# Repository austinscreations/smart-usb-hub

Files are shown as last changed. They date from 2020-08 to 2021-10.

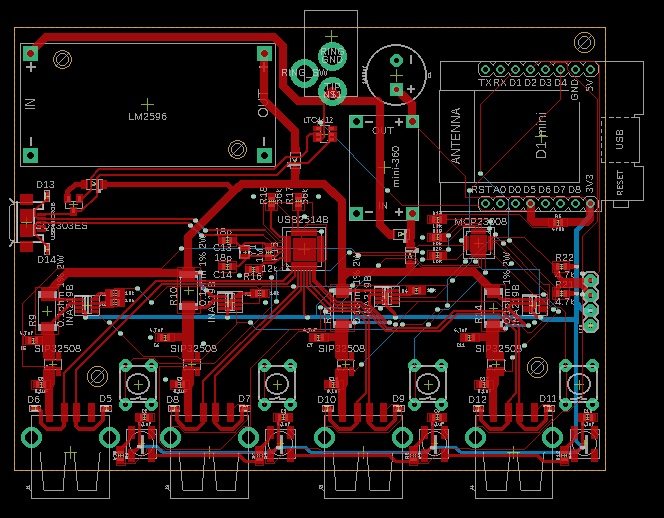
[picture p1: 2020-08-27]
version 2/design 1/pcb layout.jpg

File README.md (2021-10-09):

# smart-usb-hub
a custom usb hub for tinkers that can interface with smart home systems and provide data on power usage of a device.

2020-10-08 
added CAD files for usb2.0 for those who may want to 3d print their own case

2020-08-27
version 2 is created, has 4 usb ports, mosfet is rated for 3 amps, external power supply notifies the MCU which can allow increased current alotment in programming. eg: max 500ma under usb input vs max 5A (shared by all ports) under power supply usage (current limited by dc-dc converter)

INA219 shunt is 0.1ohm 2W 1% toleance which allows for sense current up to 3.2Amps.

version 2 now includes 4 ports using usb2514 for hub control.

board allows for buttons to be placed and allows for software control of outputs -- newpixels give the ability to iniicate status of ports. 4 pin header spot has been added for the use of an I2C LCD.

current design allows for various arengments of a custom 3D printed case that allows the hub to me mounted in various ways

current board size is 100*75mm

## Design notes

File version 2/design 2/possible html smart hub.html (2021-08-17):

## %title% Home

Home

Management

Dark Mode

ONLINE

IP Address: %ipplaceholder%

MAC Address: %macplaceholder%

Volts:

Amps:

Power:

Data:

CMND:

5.08

0.00

Disabled

Disabled

SINGLE

Toggle

Volts:

Amps:

Power:

Data:

CMND:

5.08

0.00

Disabled

Disabled

SINGLE

Toggle

Volts:

Amps:

Power:

Data:

CMND:

5.08

0.00

Disabled

Disabled

SINGLE

Toggle

Volts:

Amps:

Power:

Data:

CMND:

5.08

0.00

Disabled

Disabled

SINGLE

Toggle

%IDplaceholder% - %processorplaceholder% - %typeplaceholder%

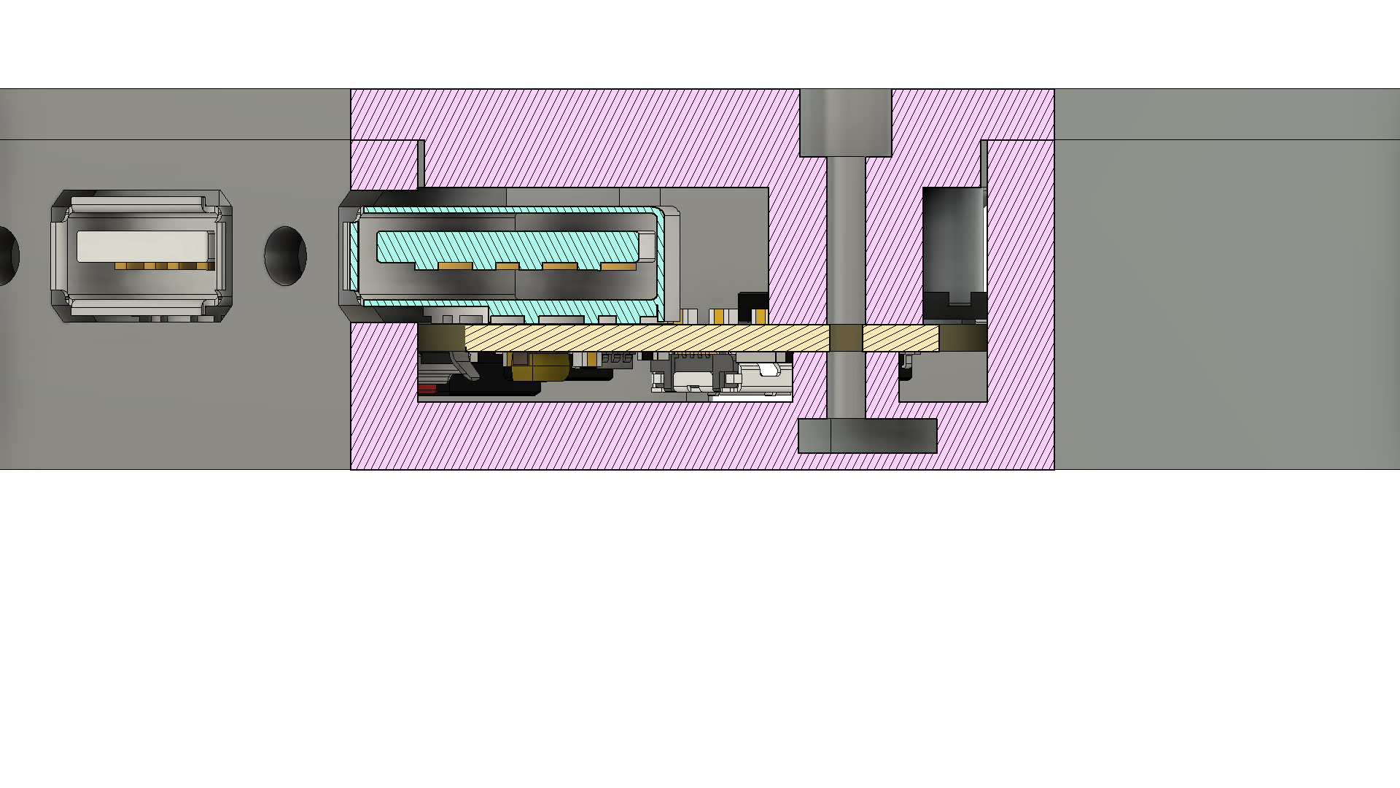
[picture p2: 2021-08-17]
version 2/design 2/cross section/corner cross section case 1.png

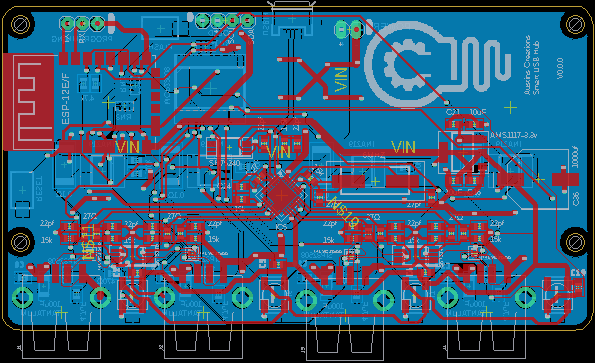
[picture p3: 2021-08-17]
version 2/design 2/v1/PCB.png

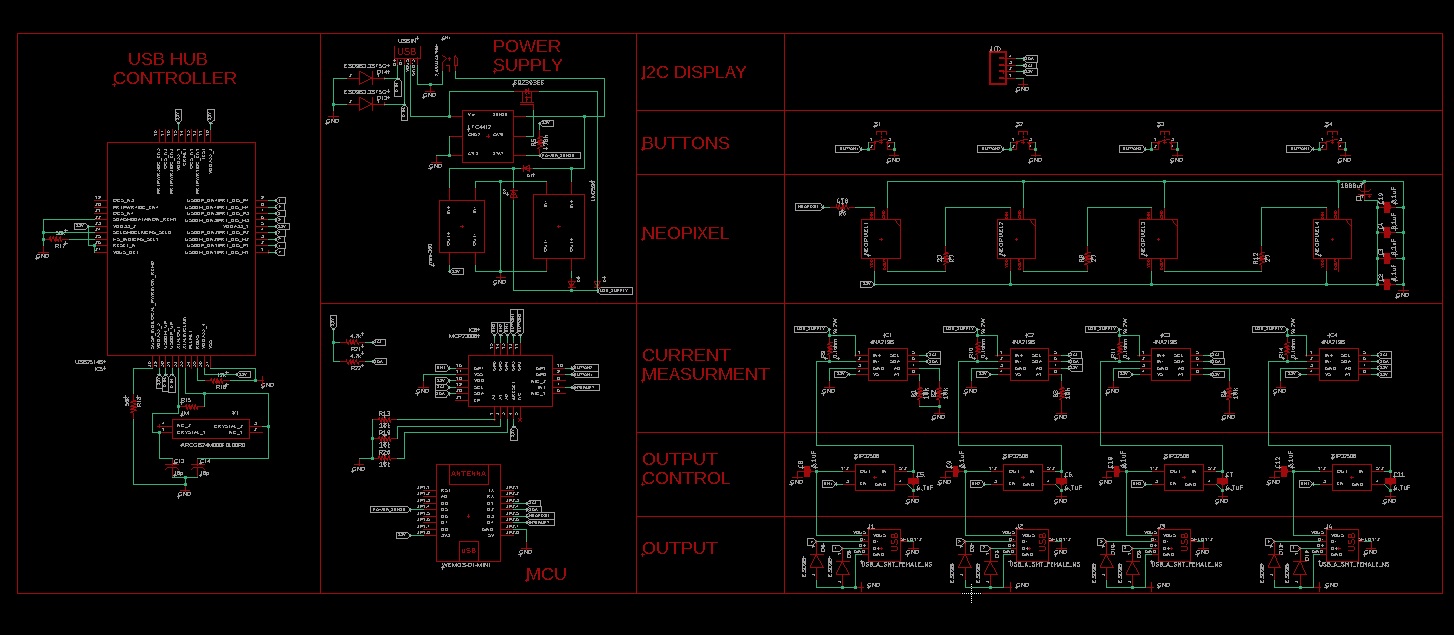
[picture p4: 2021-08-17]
version 2/design 1/schematic layout 2.jpg

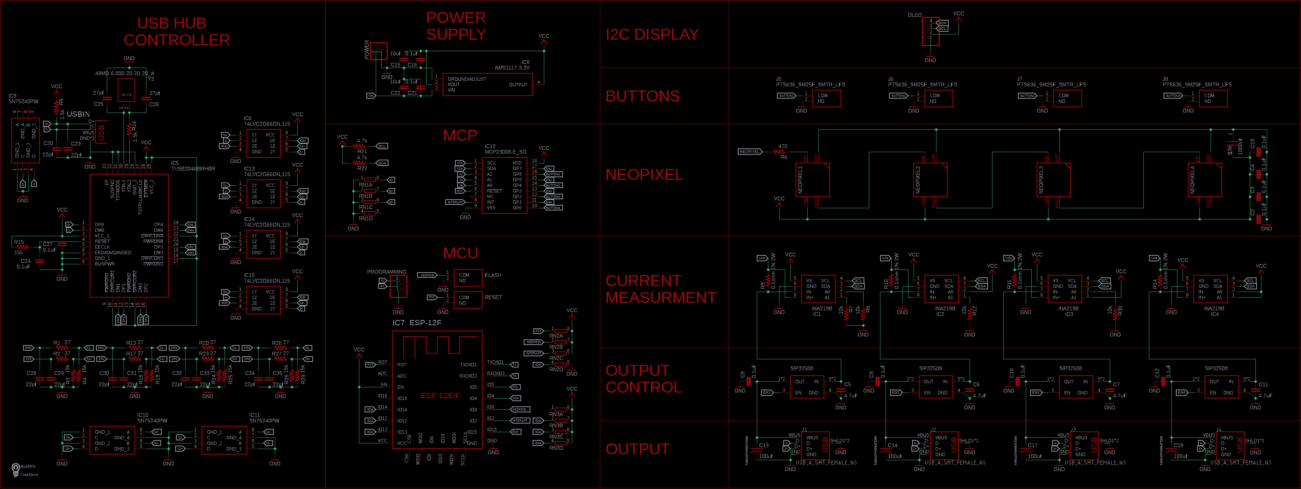
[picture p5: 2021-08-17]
version 2/design 2/v1/schematic.png

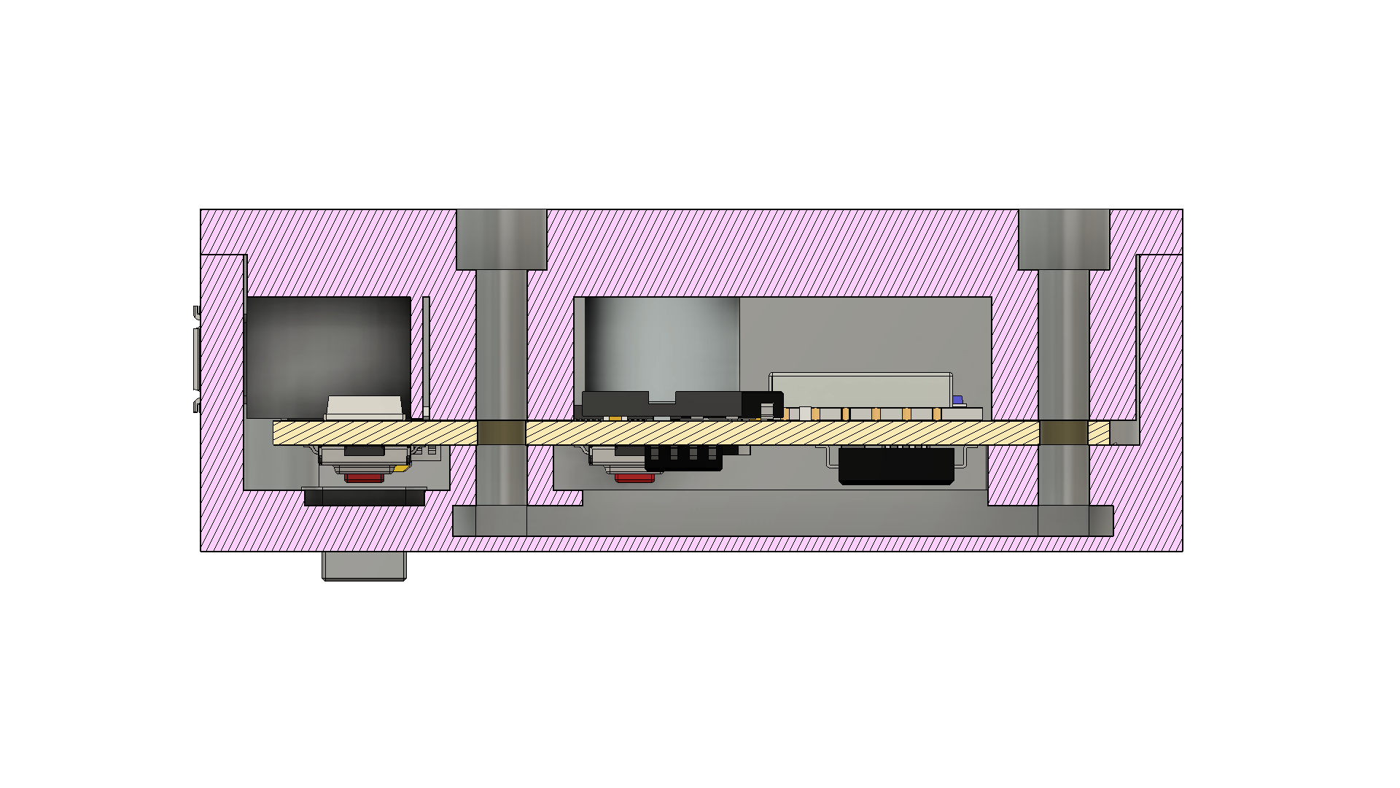
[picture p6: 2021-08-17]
version 2/design 2/cross section/side a cross section case 1.png

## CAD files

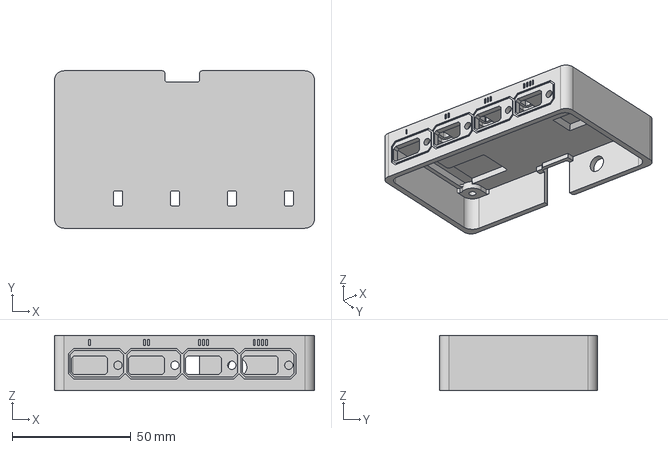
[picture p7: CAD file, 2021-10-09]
version 2/design 2/CAD/step/base.step
109.6 x 66.4 x 23.3 mm

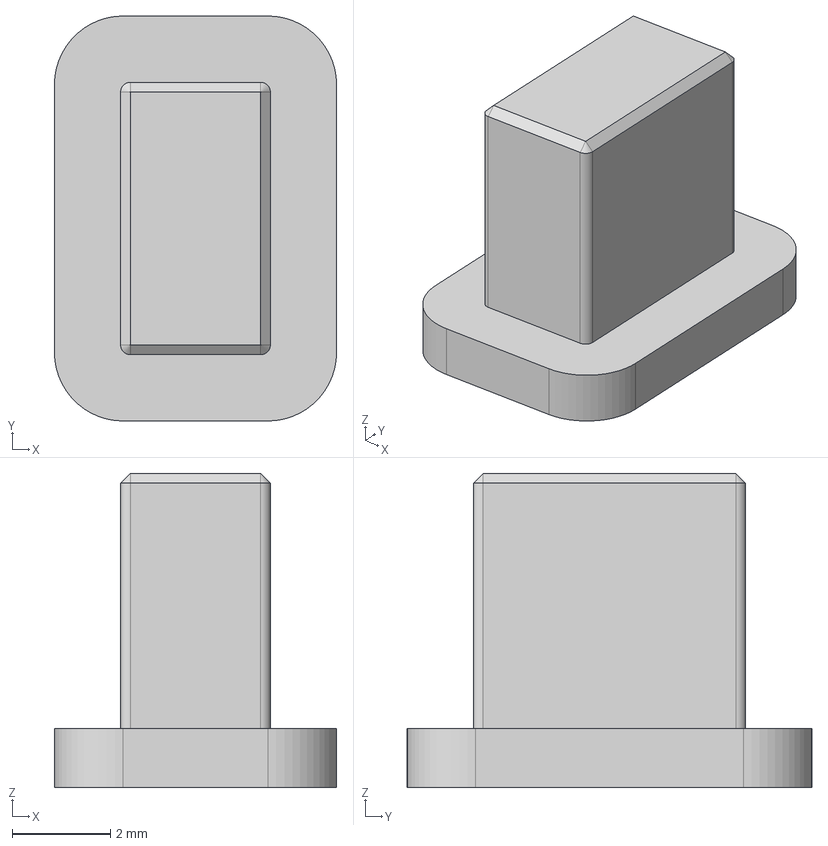
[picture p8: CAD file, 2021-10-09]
version 2/design 2/CAD/step/button.step
5.75 x 8.25 x 6.40 mm

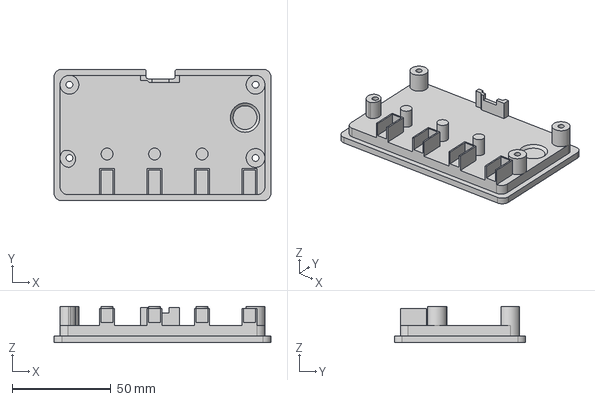
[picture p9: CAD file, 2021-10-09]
version 2/design 2/CAD/step/lid.step
109.6 x 66.4 x 18.2 mm

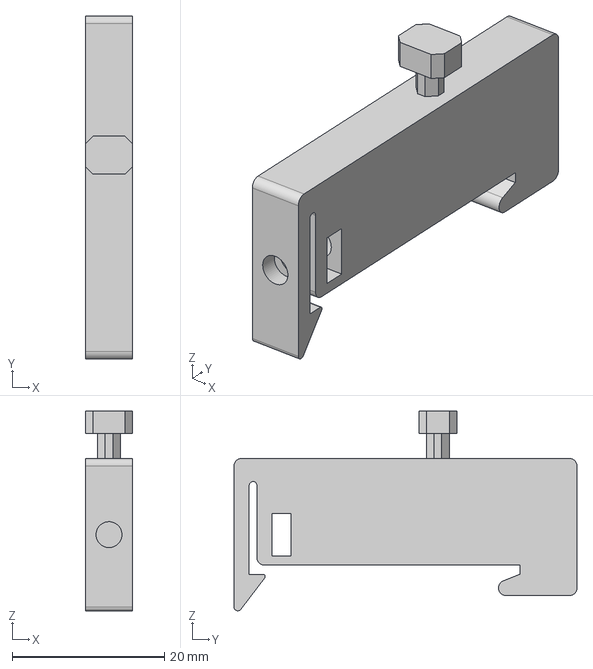
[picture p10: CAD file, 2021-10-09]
version 2/design 2/CAD/step/din rail mount.step
6.20 x 45.0 x 26.2 mm

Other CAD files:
version 2/design 2/CAD/stl/base.stl
version 2/design 2/CAD/stl/button.stl
version 2/design 2/CAD/stl/din rail mount.stl
version 2/design 2/CAD/stl/lid.stl

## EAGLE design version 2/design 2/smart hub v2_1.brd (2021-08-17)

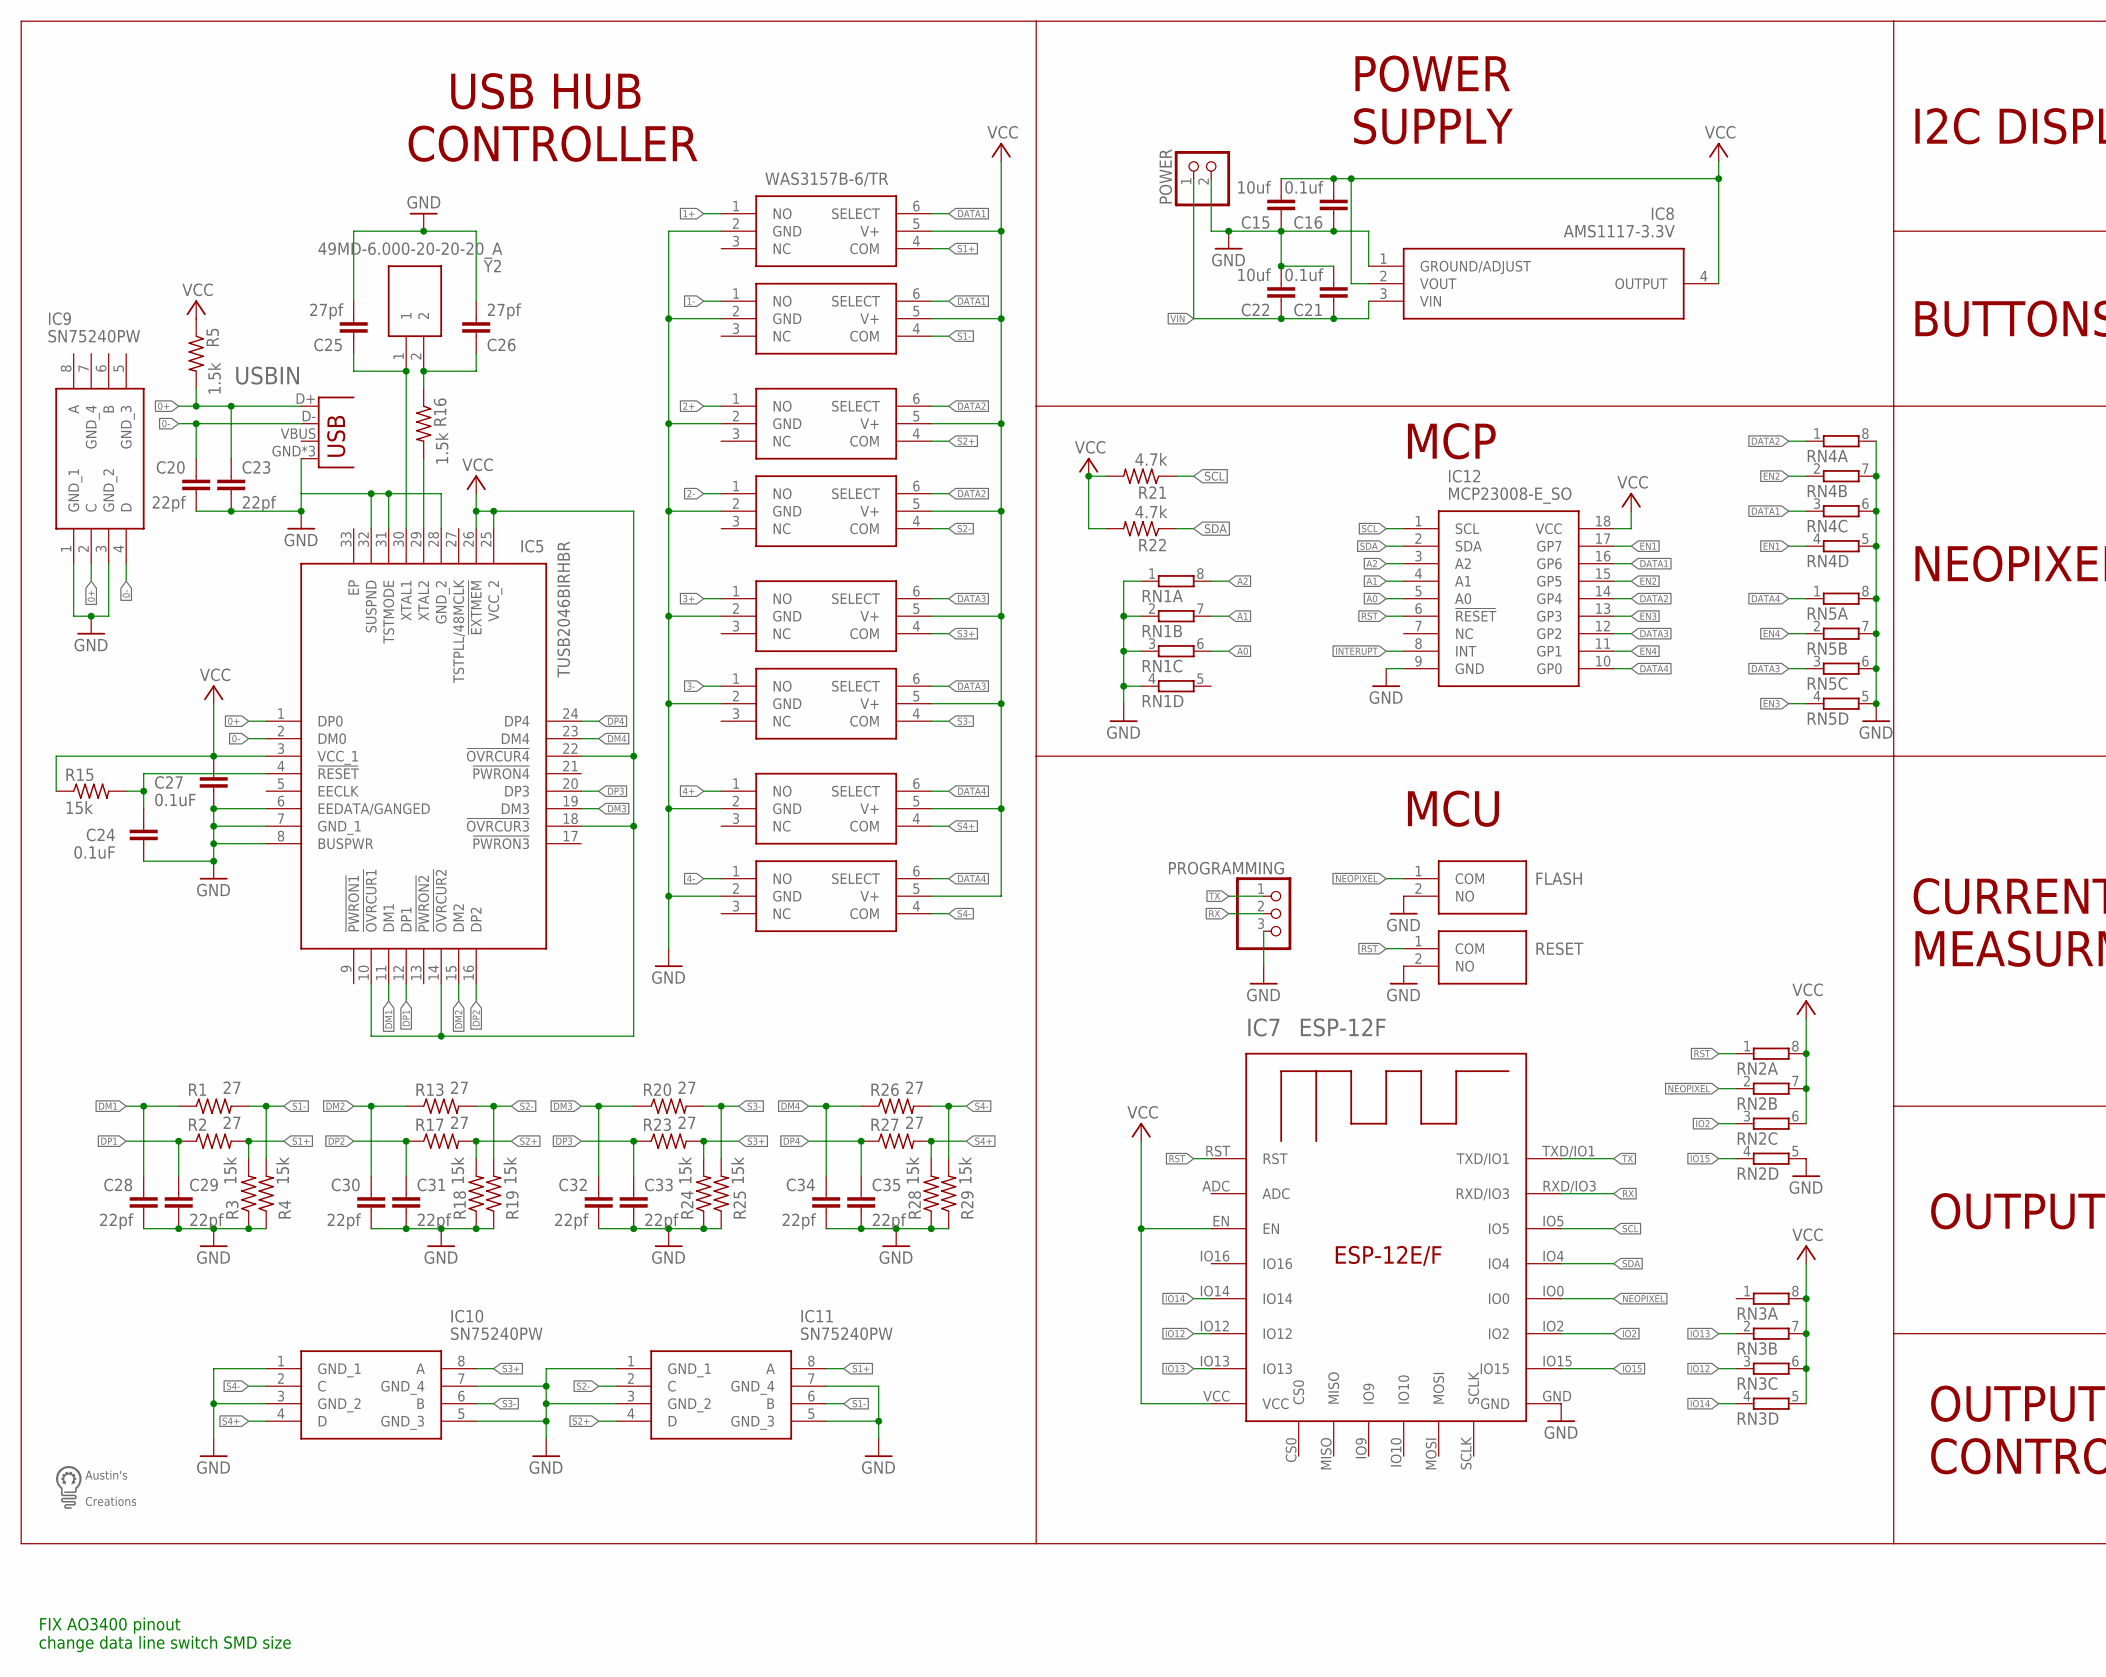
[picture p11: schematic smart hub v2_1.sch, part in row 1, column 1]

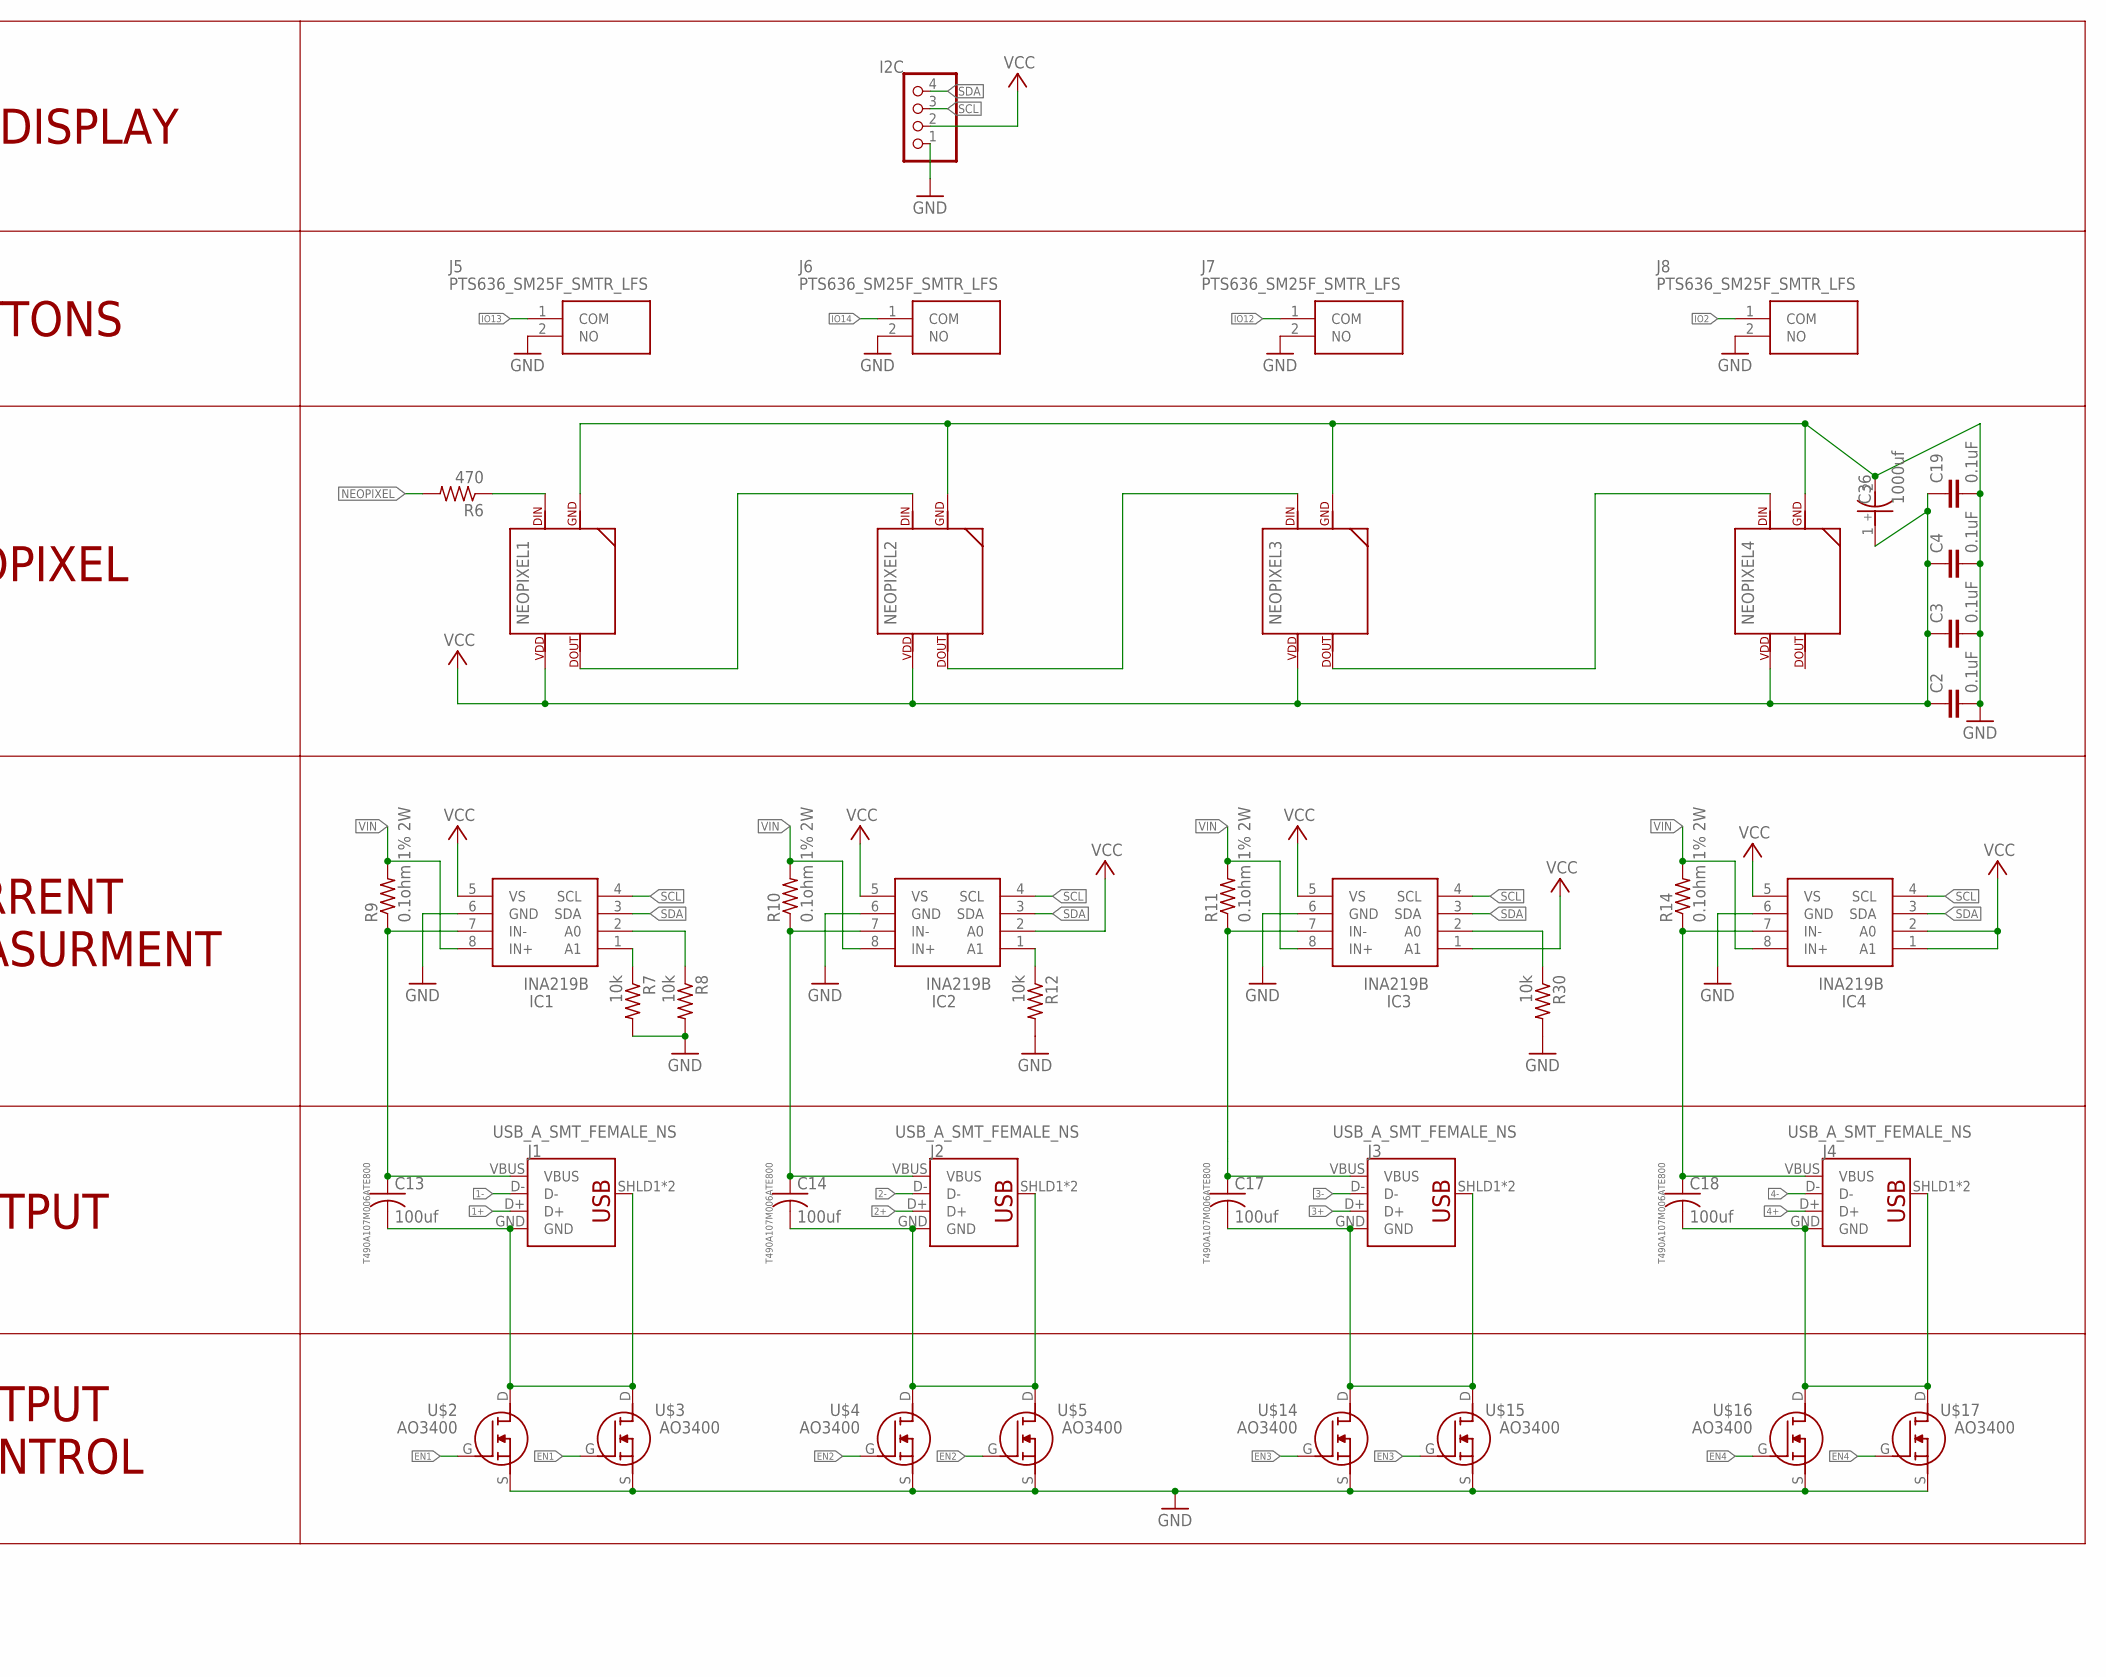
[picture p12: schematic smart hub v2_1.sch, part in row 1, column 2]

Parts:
C2, C3, C4, C19, C24, C27: 0.1uF; C0603
C13, C14, C17, C18: 100uf; C1206
C15, C22: 10uf; C0603
C16, C21: 0.1uf; C0603
C20, C23, C28, C29, C30, C31, C32, C33, C34, C35: 22pf; C0603
C25, C26: 27pf; C0603
C36: 1000uf; CAPAE1030X1050N
FLASH: PTS636_SM25F_SMTR_LFS; PTS636SM25FSMTRLFS
I2C: PINHD-1X4; 1X04
IC1, IC2, IC3, IC4: INA219B; SOIC127P600X175-8N
IC5: TUSB2046BIRHBR; QFN50P500X500X100-33N
IC7: ESP-12F; ESP-12E
IC8: AMS1117-3.3V; SOT229P700X180-4N
IC9, IC10, IC11: SN75240PW; SOP65P640X120-8N
IC12: MCP23008-E_SO; SOIC127P1030X265-18N
J1, J2, J3, J4: USB_A_SMT_FEMALE_NS; USB-A-S-NOSILK-FEMALE
J5, J6, J7, J8: PTS636_SM25F_SMTR_LFS; PTS636SM25FSMTRLFS
NEOPIXEL1, NEOPIXEL2, NEOPIXEL3, NEOPIXEL4: SK6812NEOPIXEL5050; SK6812
POWER: PINHD-1X2; 1X02
PROGRAMMING: PINHD-1X3; 1X03
R1, R2, R13, R17, R20, R23, R26, R27: 27; R0603
R3, R4, R15, R18, R19, R24, R25, R28, R29: 15k; R0603
R5, R16: 1.5k; R0603
R6: 470; R0603
R7, R8, R12, R30: 10k; R0603
R9, R10, R11, R14: 0.1ohm 1% 2W; R2512W
R21, R22: 4.7k; R0603
RESET: PTS636_SM25F_SMTR_LFS; PTS636SM25FSMTRLFS
RN1, RN2, RN3, RN4, RN5: 4R-N0603-ARC; 0603-ARC
U$1: LOGOMASSIVE
U$2, U$3, U$4, U$5, U$14, U$15, U$16, U$17: AO3400
U$6, U$7, U$8, U$9, U$10, U$11, U$12, U$13: WAS3157B-6/TR
USBIN: USB-MICROB
Y2: 49MD-6.000-20-20-20_A; 49MD6000202020A

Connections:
0+: C23.1, IC5.1 (DP0), IC9.2 (C), R5.2, USBIN.D+
0-: C20.1, IC5.2 (DM0), IC9.4 (D), USBIN.D-
1+: J1.D+, U$6.1 (NO)
1-: J1.D-, U$7.1 (NO)
2+: J2.D+, U$8.1 (NO)
2-: J2.D-, U$9.1 (NO)
3+: J3.D+, U$10.1 (NO)
3-: J3.D-, U$11.1 (NO)
4+: J4.D+, U$12.1 (NO)
4-: J4.D-, U$13.1 (NO)
A0: IC12.5 (A0), RN1.6 (2)
A1: IC12.4 (A1), RN1.7 (2)
A2: IC12.3 (A2), RN1.8 (2)
DATA1: IC12.16 (GP6), RN4.3 (1), U$6.6 (SELECT), U$7.6 (SELECT)
DATA2: IC12.14 (GP4), RN4.1, U$8.6 (SELECT), U$9.6 (SELECT)
DATA3: IC12.12 (GP2), RN5.3 (1), U$10.6 (SELECT), U$11.6 (SELECT)
DATA4: IC12.10 (GP0), RN5.1, U$12.6 (SELECT), U$13.6 (SELECT)
DM1: C28.1, IC5.11 (DM1), R1.1
DM2: C30.1, IC5.15 (DM2), R13.1
DM3: C32.1, IC5.19 (DM3), R20.1
DM4: C34.1, IC5.23 (DM4), R26.1
DP1: C29.1, IC5.12 (DP1), R2.1
DP2: C31.1, IC5.16 (DP2), R17.1
DP3: C33.1, IC5.20 (DP3), R23.1
DP4: C35.1, IC5.24 (DP4), R27.1
EN1: IC12.17 (GP7), RN4.4 (1), U$2.G, U$3.G
EN2: IC12.15 (GP5), RN4.2 (1), U$4.G, U$5.G
EN3: IC12.13 (GP3), RN5.4 (1), U$14.G, U$15.G
EN4: IC12.11 (GP1), RN5.2 (1), U$16.G, U$17.G
GND: C2.2, C3.2, C4.2, C15.1, C16.1, C19.2, C20.2, C21.2, C22.2, C23.2, C24.2, C25.2, C26.2, C27.2, C28.2, C29.2, C30.2, C31.2, C32.2, C33.2, C34.2, C35.2, C36.2 (-), FLASH.2 (NO), I2C.1, IC1.6 (GND), IC2.6 (GND), IC3.6 (GND), IC4.6 (GND), IC5.6 (EEDATA/GANGED), IC5.7 (GND_1), IC5.8 (BUSPWR), IC5.28 (GND_2), IC5.31 (TSTMODE), IC5.32 (SUSPND), IC7.GND, IC8.1 (GROUND/ADJUST), IC9.1 (GND_1), IC9.3 (GND_2), IC10.1 (GND_1), IC10.3 (GND_2), IC10.5 (GND_3), IC10.7 (GND_4), IC11.1 (GND_1), IC11.3 (GND_2), IC11.5 (GND_3), IC11.7 (GND_4), IC12.9 (GND), J5.2 (NO), J6.2 (NO), J7.2 (NO), J8.2 (NO), NEOPIXEL1.3 (GND), NEOPIXEL2.3 (GND), NEOPIXEL3.3 (GND), NEOPIXEL4.3 (GND), POWER.2, PROGRAMMING.3, R3.1, R4.1, R7.2, R8.2, R12.2, R18.1, R19.1, R24.1, R25.1, R28.1, R29.1, R30.2, RESET.2 (NO), RN1.1, RN1.2 (1), RN1.3 (1), RN1.4 (1), RN2.5 (2), RN4.5 (2), RN4.6 (2), RN4.7 (2), RN4.8 (2), RN5.5 (2), RN5.6 (2), RN5.7 (2), RN5.8 (2), U$2.S, U$3.S, U$4.S, U$5.S, U$6.2 (GND), U$7.2 (GND), U$8.2 (GND), U$9.2 (GND), U$10.2 (GND), U$11.2 (GND), U$12.2 (GND), U$13.2 (GND), U$14.S, U$15.S, U$16.S, U$17.S, USBIN.GND, USBIN.MT1 (GND), USBIN.MT2 (GND)
INTERUPT: IC12.8 (INT)
IO2: IC7.IO2, J8.1 (COM), RN2.3 (1)
IO12: IC7.IO12, J7.1 (COM), RN3.3 (1)
IO13: IC7.IO13, J5.1 (COM), RN3.2 (1)
IO14: IC7.IO14, J6.1 (COM), RN3.4 (1)
IO15: IC7.IO15, RN2.4 (1)
unnamed: C13.2, J1.GND, J1.SHLD1 (SHIELD), J1.SHLD2 (SHIELD), U$2.D, U$3.D
unnamed: C14.2, J2.GND, J2.SHLD1 (SHIELD), J2.SHLD2 (SHIELD), U$4.D, U$5.D
unnamed: C25.1, IC5.30 (XTAL1), Y2.1
unnamed: C24.1, IC5.4 (!RESET), R15.2
unnamed: C26.1, R16.1, Y2.2
unnamed: C17.2, J3.GND, J3.SHLD1 (SHIELD), J3.SHLD2 (SHIELD), U$14.D, U$15.D
unnamed: IC5.29 (XTAL2), R16.2
unnamed: NEOPIXEL1.2 (DOUT), NEOPIXEL2.4 (DIN)
unnamed: NEOPIXEL2.2 (DOUT), NEOPIXEL3.4 (DIN)
unnamed: C18.2, J4.GND, J4.SHLD1 (SHIELD), J4.SHLD2 (SHIELD), U$16.D, U$17.D
unnamed: IC3.2 (A0), R30.1
unnamed: IC2.1 (A1), R12.1
unnamed: IC1.1 (A1), R7.1
unnamed: IC1.2 (A0), R8.1
unnamed: NEOPIXEL1.4 (DIN), R6.1
unnamed: C13.1, IC1.7 (IN-), J1.VBUS, R9.1
unnamed: NEOPIXEL3.2 (DOUT), NEOPIXEL4.4 (DIN)
unnamed: C14.1, IC2.7 (IN-), J2.VBUS, R10.1
unnamed: C17.1, IC3.7 (IN-), J3.VBUS, R11.1
unnamed: C18.1, IC4.7 (IN-), J4.VBUS, R14.1
NEOPIXEL: FLASH.1 (COM), IC7.IO0, R6.2, RN2.2 (1)
RST: IC7.RST, IC12.6 (!RESET), RESET.1 (COM), RN2.1
RX: IC7.RXD/IO3, PROGRAMMING.2
S1+: IC11.8 (A), R2.2, R3.2, U$6.4 (COM)
S1-: IC11.6 (B), R1.2, R4.2, U$7.4 (COM)
S2+: IC11.4 (D), R17.2, R18.2, U$8.4 (COM)
S2-: IC11.2 (C), R13.2, R19.2, U$9.4 (COM)
S3+: IC10.8 (A), R23.2, R24.2, U$10.4 (COM)
S3-: IC10.6 (B), R20.2, R25.2, U$11.4 (COM)
S4+: IC10.4 (D), R27.2, R28.2, U$12.4 (COM)
S4-: IC10.2 (C), R26.2, R29.2, U$13.4 (COM)
SCL: I2C.3, IC1.4 (SCL), IC2.4 (SCL), IC3.4 (SCL), IC4.4 (SCL), IC7.IO5, IC12.1 (SCL), R21.1
SDA: I2C.4, IC1.3 (SDA), IC2.3 (SDA), IC3.3 (SDA), IC4.3 (SDA), IC7.IO4, IC12.2 (SDA), R22.1
TX: IC7.TXD/IO1, PROGRAMMING.1
VCC: C2.1, C3.1, C4.1, C15.2, C16.2, C19.1, C27.1, C36.1 (+), I2C.2, IC1.5 (VS), IC2.2 (A0), IC2.5 (VS), IC3.1 (A1), IC3.5 (VS), IC4.1 (A1), IC4.2 (A0), IC4.5 (VS), IC5.3 (VCC_1), IC5.10 (!OVRCUR1), IC5.14 (!OVRCUR2), IC5.18 (!OVRCUR3), IC5.22 (!OVRCUR4), IC5.25 (VCC_2), IC5.26 (!EXTMEM), IC7.EN, IC7.VCC, IC8.2 (VOUT), IC8.4 (OUTPUT), IC12.18 (VCC), NEOPIXEL1.1 (VDD), NEOPIXEL2.1 (VDD), NEOPIXEL3.1 (VDD), NEOPIXEL4.1 (VDD), R5.1, R15.1, R21.2, R22.2, RN2.6 (2), RN2.7 (2), RN2.8 (2), RN3.5 (2), RN3.6 (2), RN3.7 (2), RN3.8 (2), U$6.5 (V+), U$7.5 (V+), U$8.5 (V+), U$9.5 (V+), U$10.5 (V+), U$11.5 (V+), U$12.5 (V+), U$13.5 (V+)
VIN: C21.1, C22.1, IC1.8 (IN+), IC2.8 (IN+), IC3.8 (IN+), IC4.8 (IN+), IC8.3 (VIN), POWER.1, R9.2, R10.2, R11.2, R14.2

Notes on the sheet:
I2C DISPLAY
BUTTONS
NEOPIXEL
CURRENT MEASURMENT
OUTPUT CONTROL
OUTPUT
POWER SUPPLY
USB HUB CONTROLLER
MCU
MCP
T490A107M006ATE800
FIX AO3400 pinout change data line switch SMD size

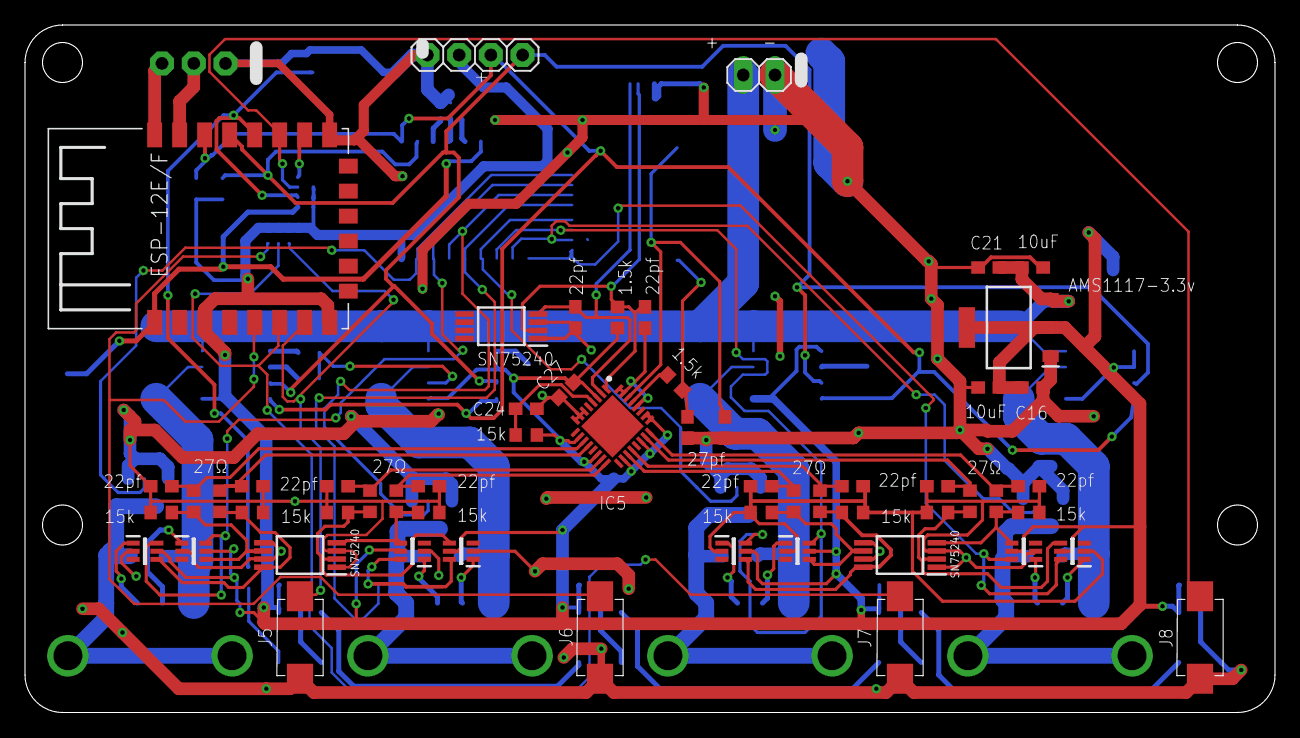
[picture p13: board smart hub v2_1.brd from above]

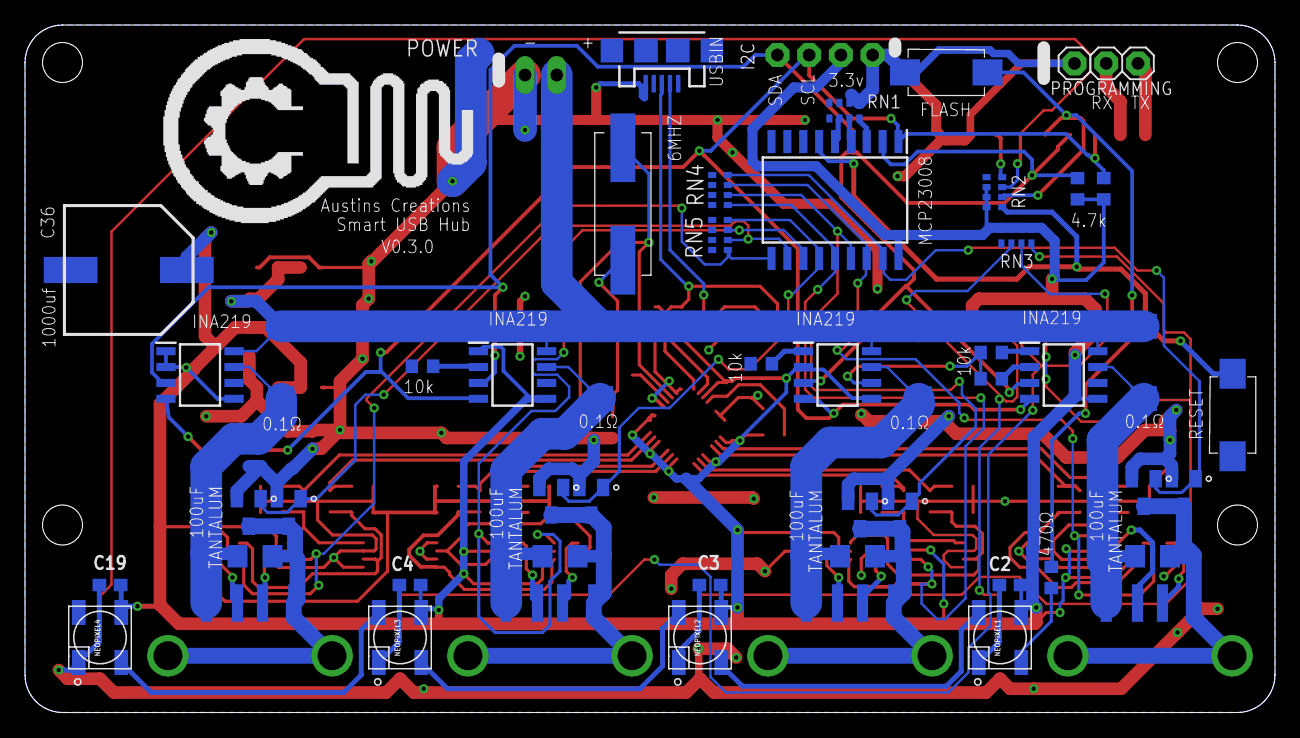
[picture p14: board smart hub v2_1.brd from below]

Board: 2 copper layers, 100.0 x 55.0 mm, 109 parts (52 on the bottom side), 71 nets.

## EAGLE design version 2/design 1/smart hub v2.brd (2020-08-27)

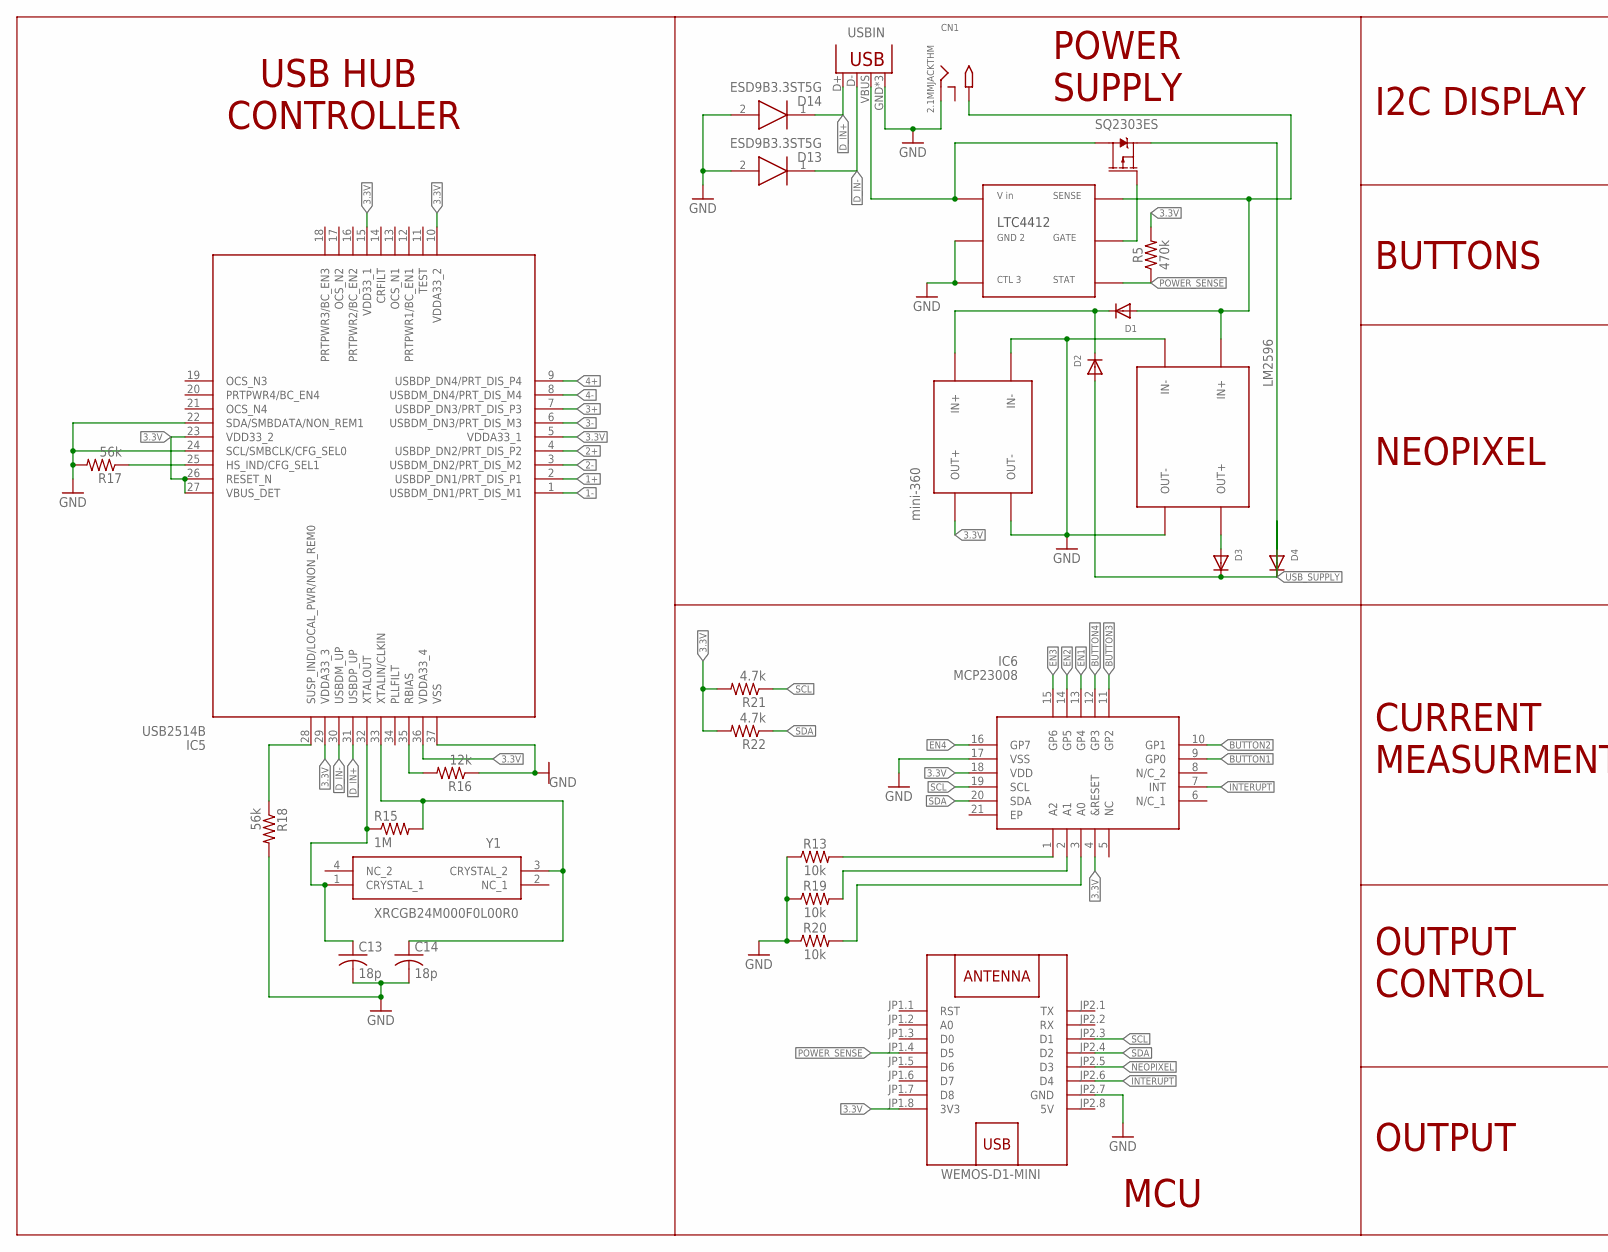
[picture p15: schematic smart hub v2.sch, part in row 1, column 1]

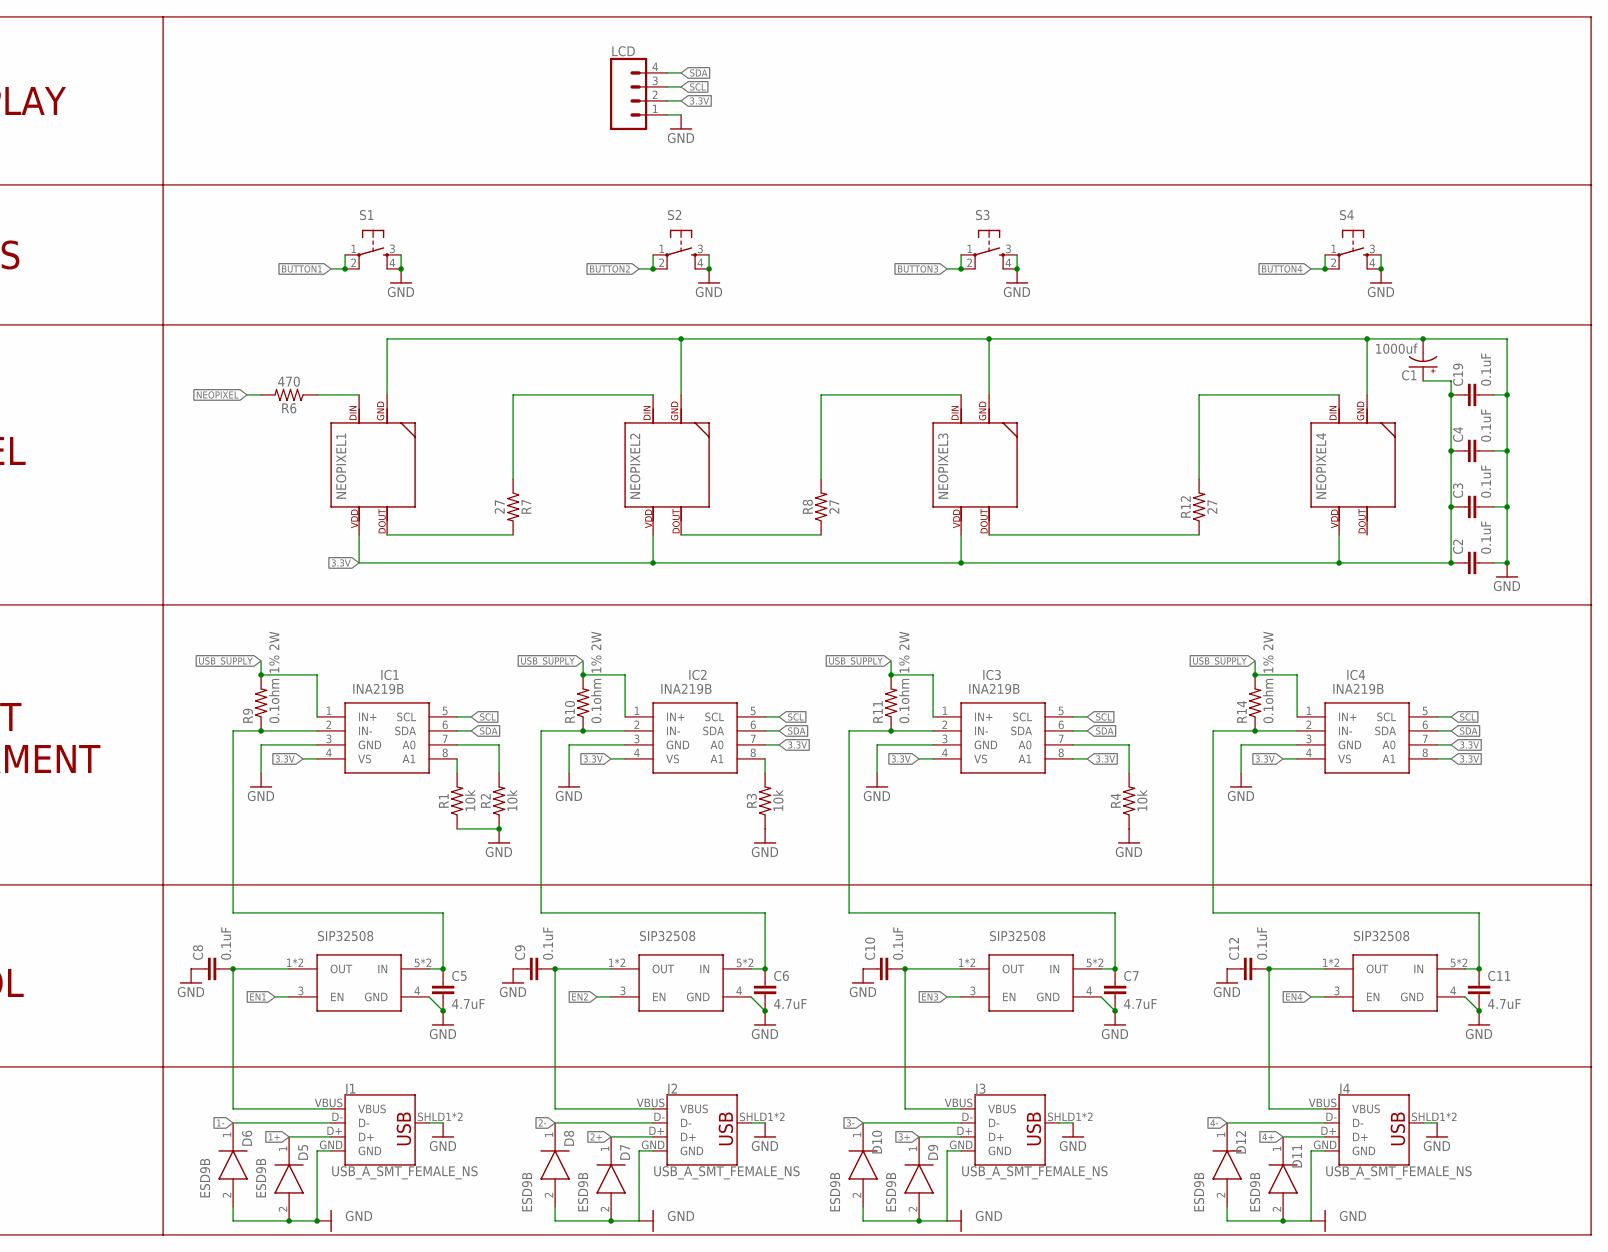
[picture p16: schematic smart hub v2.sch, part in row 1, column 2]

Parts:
C1: 1000uf; CPOL-RADIAL-5MM-10MM-KIT
C2, C3, C4, C8, C9, C10, C12, C19: 0.1uF; 0603
C5, C6, C7, C11: 4.7uF; 0603
C13, C14: 18p; C0603
CN1: 2.1MMJACKTHM; PJ-102A
D1, D2, D3, D4: DIODE_SOD-123FL; SOD-123FL
D5, D6, D7, D8, D9, D10, D11, D12: ESD9B; SODFL1006X40N
D13, D14: ESD9B3.3ST5G; SODFL1006X40N
IC1, IC2, IC3, IC4: INA219B; SOT65P280X145-8N
IC5: USB2514B; QFN50P600X600X100-37N
IC6: MCP23008; QFN50P400X400X100-21N
J1, J2, J3, J4: USB_A_SMT_FEMALE_NS; USB-A-S-NOSILK-FEMALE
LCD: CONN_04; 1X04
LTC4412: LTC4412; TSOT23-6
NEOPIXEL1, NEOPIXEL2, NEOPIXEL3, NEOPIXEL4: SK6812NEOPIXEL5050; SK6812
R1, R2, R3, R4, R13, R19, R20: 10k; 0603
R5: 470k; 0603
R6: 470; 0603
R7, R8, R12: 27; 0603
R9, R10, R11, R14: 0.1ohm 1% 2W; R2512W
R15: 1M; R0603
R16: 12k; R0603
R17, R18: 56k; R0603
R21, R22: 4.7k; R0603
S1, S2, S3, S4: TAC_SWITCHPTH; TACTILE-PTH
U$1: WEMOS-D1-MINI
U$2: SQ2303ES; SOT23
U$3, U$4, U$5, U$8: SIP32508; SOT23-6
U$6: LM2596; DC-DC-STEP-DOWN-LM2596
U$7: mini-360; DC-DC-STEP-DOWN-MP2307
USBIN: USB-MICROB
Y1: XRCGB24M000F0L00R0; XRCGB24

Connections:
1+: D5.1 (K), IC5.2 (USBDP_DN1/PRT_DIS_P1), J1.D+
1-: D6.1 (K), IC5.1 (USBDM_DN1/PRT_DIS_M1), J1.D-
2+: D7.1 (K), IC5.4 (USBDP_DN2/PRT_DIS_P2), J2.D+
2-: D8.1 (K), IC5.3 (USBDM_DN2/PRT_DIS_M2), J2.D-
3+: D9.1 (K), IC5.7 (USBDP_DN3/PRT_DIS_P3), J3.D+
3-: D10.1 (K), IC5.6 (USBDM_DN3/PRT_DIS_M3), J3.D-
3.3V: C1.+, C2.1, C3.1, C4.1, C19.1, IC1.4 (VS), IC2.4 (VS), IC2.7 (A0), IC3.4 (VS), IC3.8 (A1), IC4.4 (VS), IC4.7 (A0), IC4.8 (A1), IC5.5 (VDDA33_1), IC5.10 (VDDA33_2), IC5.15 (VDD33_1), IC5.23 (VDD33_2), IC5.26 (RESET_N), IC5.27 (VBUS_DET), IC5.29 (VDDA33_3), IC5.36 (VDDA33_4), IC6.4 (&RESET), IC6.18 (VDD), LCD.2, NEOPIXEL1.1 (VDD), NEOPIXEL2.1 (VDD), NEOPIXEL3.1 (VDD), NEOPIXEL4.1 (VDD), R5.2, R21.2, R22.2, U$1.JP1.8 (3V3), U$7.OUT+
4+: D11.1 (K), IC5.9 (USBDP_DN4/PRT_DIS_P4), J4.D+
4-: D12.1 (K), IC5.8 (USBDM_DN4/PRT_DIS_M4), J4.D-
5V: U$1.JP2.8 (5V)
BUTTON1: IC6.9 (GP0), S1.1, S1.2
BUTTON2: IC6.10 (GP1), S2.1, S2.2
BUTTON3: IC6.11 (GP2), S3.1, S3.2
BUTTON4: IC6.12 (GP3), S4.1, S4.2
D_IN+: D14.1 (K), IC5.31 (USBDP_UP), USBIN.D+
D_IN-: D13.1 (K), IC5.30 (USBDM_UP), USBIN.D-
EN1: IC6.13 (GP4), U$3.3 (EN)
EN2: IC6.14 (GP5), U$4.3 (EN)
EN3: IC6.15 (GP6), U$5.3 (EN)
EN4: IC6.16 (GP7), U$8.3 (EN)
GND: C1.-, C2.2, C3.2, C4.2, C5.2, C6.2, C7.2, C8.1, C9.1, C10.1, C11.2, C12.1, C13.2, C14.2, C19.2, CN1.RING, D5.2 (A), D6.2 (A), D13.2 (A), D14.2 (A), IC1.3 (GND), IC2.3 (GND), IC3.3 (GND), IC4.3 (GND), IC5.22 (SDA/SMBDATA/NON_REM1), IC5.24 (SCL/SMBCLK/CFG_SEL0), IC5.37 (VSS), IC6.17 (VSS), J1.GND, J1.SHLD1 (SHIELD), J1.SHLD2 (SHIELD), J2.SHLD1 (SHIELD), J2.SHLD2 (SHIELD), J3.SHLD1 (SHIELD), J3.SHLD2 (SHIELD), J4.SHLD1 (SHIELD), J4.SHLD2 (SHIELD), LCD.1, LTC4412.2, LTC4412.3, NEOPIXEL1.3 (GND), NEOPIXEL2.3 (GND), NEOPIXEL3.3 (GND), NEOPIXEL4.3 (GND), R1.1, R2.1, R3.1, R4.1, R13.1, R16.1, R17.2, R18.2, R19.1, R20.1, S1.3, S1.4, S2.3, S2.4, S3.3, S3.4, S4.3, S4.4, U$1.JP2.7 (GND), U$3.4 (GND), U$4.4 (GND), U$5.4 (GND), U$6.IN-, U$6.OUT-, U$7.IN-, U$7.OUT-, U$8.4 (GND), USBIN.GND, USBIN.MT1 (GND), USBIN.MT2 (GND)
GND1: D7.2 (A), D8.2 (A), J2.GND
GND2: D9.2 (A), D10.2 (A), J3.GND
GND3: D11.2 (A), D12.2 (A), J4.GND
INTERUPT: IC6.7 (INT), U$1.JP2.6 (D4)
unnamed: CN1.TIP, D1.A, LTC4412.6, U$6.IN+
unnamed: D1.C, D2.C, U$7.IN+
unnamed: D4.A, U$2.2 (S)
unnamed: D3.A, U$6.OUT+
unnamed: LTC4412.5, U$2.1 (G)
unnamed: NEOPIXEL2.4 (DIN), R7.1
unnamed: LTC4412.1, U$2.3 (D), USBIN.VBUS
unnamed: NEOPIXEL3.4 (DIN), R8.2
unnamed: NEOPIXEL1.2 (DOUT), R7.2
unnamed: NEOPIXEL2.2 (DOUT), R8.1
unnamed: C5.1, IC1.2 (IN-), R9.1, U$3.5 (IN), U$3.6 (IN)
unnamed: C6.1, IC2.2 (IN-), R10.1, U$4.5 (IN), U$4.6 (IN)
unnamed: IC3.7 (A0), R4.2
unnamed: IC2.8 (A1), R3.2
unnamed: IC1.8 (A1), R1.2
unnamed: IC1.7 (A0), R2.2
unnamed: NEOPIXEL1.4 (DIN), R6.1
unnamed: NEOPIXEL4.4 (DIN), R12.2
unnamed: C7.1, IC3.2 (IN-), R11.1, U$5.5 (IN), U$5.6 (IN)
unnamed: NEOPIXEL3.2 (DOUT), R12.1
unnamed: C10.2, J3.VBUS, U$5.1 (OUT), U$5.2 (OUT)
unnamed: C9.2, J2.VBUS, U$4.1 (OUT), U$4.2 (OUT)
unnamed: IC6.1 (A2), R13.2
unnamed: IC6.2 (A1), R19.2
unnamed: C11.1, IC4.2 (IN-), R14.1, U$8.5 (IN), U$8.6 (IN)
unnamed: C12.2, J4.VBUS, U$8.1 (OUT), U$8.2 (OUT)
unnamed: C13.1, IC5.32 (XTALOUT), R15.1, Y1.1 (CRYSTAL_1)
unnamed: C14.1, IC5.33 (XTALIN/CLKIN), R15.2, Y1.3 (CRYSTAL_2)
unnamed: IC5.25 (HS_IND/CFG_SEL1), R17.1
unnamed: IC5.28 (SUSP_IND/LOCAL_PWR/NON_REM0), R18.1
unnamed: IC5.35 (RBIAS), R16.2
unnamed: IC6.3 (A0), R20.2
unnamed: C8.2, J1.VBUS, U$3.1 (OUT), U$3.2 (OUT)
NEOPIXEL: R6.2, U$1.JP2.5 (D3)
POWER_SENSE: LTC4412.4, R5.1, U$1.JP1.4 (D5)
SCL: IC1.5 (SCL), IC2.5 (SCL), IC3.5 (SCL), IC4.5 (SCL), IC6.19 (SCL), LCD.3, R21.1, U$1.JP2.3 (D1)
SDA: IC1.6 (SDA), IC2.6 (SDA), IC3.6 (SDA), IC4.6 (SDA), IC6.20 (SDA), LCD.4, R22.1, U$1.JP2.4 (D2)
USB_SUPPLY: D2.A, D3.C, D4.C, IC1.1 (IN+), IC2.1 (IN+), IC3.1 (IN+), IC4.1 (IN+), R9.2, R10.2, R11.2, R14.2

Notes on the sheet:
LTC4412
I2C DISPLAY
BUTTONS
NEOPIXEL
CURRENT MEASURMENT
OUTPUT CONTROL
OUTPUT
POWER SUPPLY
MCU
USB HUB CONTROLLER

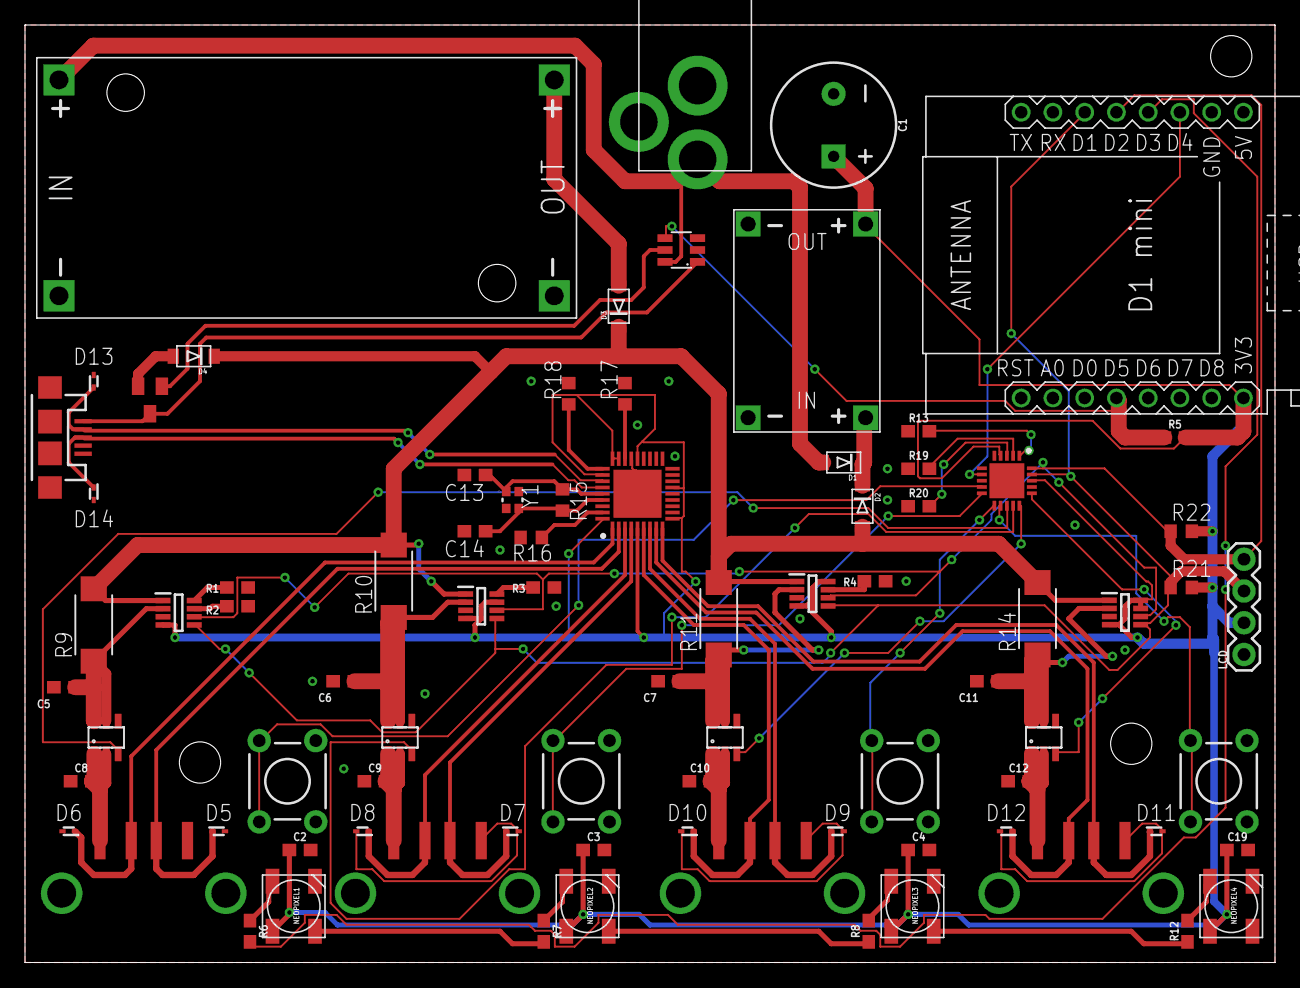
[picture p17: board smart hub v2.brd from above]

Board: 2 copper layers, 100.0 x 75.0 mm, 82 parts (0 on the bottom side), 62 nets.

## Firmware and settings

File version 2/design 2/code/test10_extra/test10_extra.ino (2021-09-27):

/*
 * Started 2021-08-21
 * 
 * GOAL: have homepage interface refreshed
 * 
 * to be done:
 * send data via mqtt                                                        // done - test5
 * MQTT inputs                                                               // done - test7
 * over ride mode                                                            // done - test7
 * OTA + config                                                              // done
 *  - setup main setup and loop functions                                    // done
 *  - adjust json save functions                                             // done
 *  - adjust website form params                                             // done
 *  - adjust wifi save string function                                       // done
 *  - add mqtt save function                                                 // done
 *  - add config items to %processor%                                        // done
 *  
 * debug output
 *  - Buttons                                                                // 
 *  - Buttons WIFI                                                           // 
 *  - neopixel for wifi and mqtt                                             // 
 *  - mqtt payload / callback                                                // 
 *  - current                                                                // 
 *  - voltage                                                                // 
 *  - json                                                                   // done
 *  
 * webpage                                                                   // 
 * 
 * 
 * add / double check comments                                               // 
 * 
 * 
 * 
 * add more / better debug output                                            // done - in manager test 8 OTA / AP / WEB
 * 
 * over current port state = 10 / double flash blue
 * over current hub        = 11 / double flash purple
 * 
 */

#include "FS.h"
#include "ESPAsyncWebServer.h"
#include <ArduinoJson.h>
#include "debug.h"             // embeded degug library


#include "config.h"             // config information
#include "factory_settings.h"   // factory reset config

#if defined(ESP8266)
    #include "ESP8266WiFi.h"
    #include "ESPAsyncTCP.h"
    #include "flash_hal.h"
    #include <LittleFS.h>
#elif defined(ESP32)
    #include "WiFi.h"
    #include "AsyncTCP.h"
    #include "Update.h"
    #include "esp_int_wdt.h"
    #include "esp_task_wdt.h"
    #include "LITTLEFS.h"
#endif

#include <PubSubClient.h>       // For MQTT
#include "buttons.h"            // embeded button library for handling multi press events
#include "varibles.h"           // non-edited varibles
#include <Adafruit_MCP23008.h>  // For Output Enables
#include <Adafruit_INA219.h>    // For Current Measurements
#include <Adafruit_NeoPixel.h>  // for SK6812 RGBW LEDs

/* WEB PAGES */
#include "homepage.h"           // website home page
#include "management.h"         // Website OTA page
#include "config_page.h"        // ESP html configuration page
#include "failed.h"             // Something failed webpage
#include "reboot.h"             // Website - ESP rebooting
#include "finished.h"           // OTA success Webpage
#include "config_finished.h"    // Saved Config Message Webpage
#include "factory_html.h"       // Factory Reset Performed Webpage

AsyncWebServer server(80);      // declare ASYNC server library
AsyncWebSocket ws("/ws");       // declare web socket

/* library constructors here */
WiFiClient espClient;
PubSubClient client(espClient);
Adafruit_NeoPixel strip(LED_COUNT, LED_PIN, LED_TYPE + NEO_KHZ800);
multiButton button = multiButton();                // regular GPIO button
Adafruit_MCP23008 mcp;
Adafruit_INA219 ina219_0(0x40);
Adafruit_INA219 ina219_1(0x41);
Adafruit_INA219 ina219_2(0x44);
Adafruit_INA219 ina219_3(0x45);

#include "neopixel.h"           // embedded animations for neopixels          should be cpp

#include "wifisave.h"           // Saving new Config information              should be cpp
#include "processing_items.h"   // processor for webpage varibles             should be cpp
#include "customserver.h"       // manages the ASYNC server webpage serving   should be cpp
#include "wifi.h"               // manages the wifi and AP conenctions        should be cpp

#include "ESP_Color.h"          // embede library for changing RGB - HSV - HEX for webpage
#include "web_json.h"           // embedded handling of websocket json

#include "ina219.h"             // embedded functions for INA219 measurements should be cpp
#include "press.h"              // emdedded functions for handling port state should be cpp
#include "mqtt_setup.h"         // emdedded functions for wifi and mqtt       should be cpp

/* handlers for button callback */
char * getMqttButtonAction(uint8_t state)
{
  // Determine what action we need to publish
  static char action[7];
  switch (state)
  {
    case BUTTON_HOLD_STATE:
      sprintf_P(action, PSTR("HOLD"));
      break;
    case 1:
      sprintf_P(action, PSTR("SINGLE"));
      break;
    case 2:
      sprintf_P(action, PSTR("DOUBLE"));
      break;
    case 3:
      sprintf_P(action, PSTR("TRIPLE"));
      break;
    case 4:
      sprintf_P(action, PSTR("QUAD"));
      break;
    case 5:
      sprintf_P(action, PSTR("PENTA"));
      break;
    default:
      sprintf_P(action, PSTR("ERROR"));
      break;
  }
  return action;
}

void buttonPressed(uint8_t button, uint8_t state)
{
 
  // Determine the port, switch, and button numbers (1-based)
  uint8_t raw_button =  button;
  uint8_t mqtt_button = raw_button + 1;

  if (overrideMODE == false) // not in override mode --- when in override mode we only send the data out via mqtt
  {
    last_press[raw_button] = state; 
    lastINAread[raw_button] = millis(); // resets the time readout for reading current usage
    lastINAmqtt[raw_button] = millis(); // resets the time for the for mqtt current readout
  }
  else                                  // in override mode still check for triple press reset of over current port / hub
  {
    if (port_state[raw_button] == 10 )  // we are in an over port
    {
      if (state == 3)                   // make sure it was a triple press
      {
        last_press[raw_button] = state; // send triple press for reset from current cut off
      }
    }
    if (port_state[raw_button] == 11 )  // over current hub
    {
      if (state == 3)                   // make sure it was a triple press
      {
        last_press[raw_button] = state; // send triple press for reset from current cut off  
      }
    }
  }

  if (DEBUG_BUTTONS)
  {
    Serial.print(F("Press detected: "));
    Serial.print(F(" BUTTON: "));
    Serial.print(mqtt_button);
    Serial.print(F(" STATE: "));
    Serial.print(state);
    Serial.print(F(" ACTION: "));
    Serial.println(getMqttButtonAction(state));
  }
      sprintf_P(mqtt_button_buffer, PSTR("{\"BUTTON\":%d, \"ACTION\":\"%s\"}"), mqtt_button, getMqttButtonAction(state));
      client.publish(out_topic1, mqtt_button_buffer);
      Serial.print("mqtt output: ");
      Serial.println(mqtt_button_buffer);
}


void setup() {
  Serial.begin(115200);
  delay(500);                       // There has GOT to be a better way!!!
  DEBUG_Boot();                     // print device is booting

  DEBUG_Reset();                    // print reset reason

  parameterSETUP();                 // wifisave.h

  mcp.begin();                      //             - start MCP - controls data lines and power fets
    for (uint8_t o = 0; o < 8; o++) // set all the MCP pins to output
  {
    mcp.pinMode(o, OUTPUT);
  }

  portlockout();                    // press.h      - resets all ports to off

  strip.begin();                    //              - INITIALIZE NeoPixel strip object (REQUIRED)
  strip.setBrightness(brightness);  //              - set strip brightness
  colorWipe(0,0,0,0);               // neopixel.h   - turn all the led's off

  INA_SETUP();                      // ina219.h     - setup the INA sensors

  wifi_start();                     // start wifi   - will start AP / WiFi as needed - wifi.h

  initWebSocket();                  // start websocket

  customInit();                     // start server - starts ASYNC server - customserver.h


   if (strcmp(mqtt_broker, "0") == 0)               // no broker declared
    {Serial.println("no broker declared");}
    else                                            // broker declared
    {
      settopics();                                  // mqtt_setup.h - set mqtt topics
    client.setServer(mqtt_broker, mqtt_port);
    client.setCallback(callback);
    }


  for (uint8_t i = 0; i < 4; i++)   // setup all the GPIO buttons
  {
   button.setup(i, buttons[i]);     // buttons.h - setup gpio butons
  }

  button.onButtonPressed(buttonPressed);

  DEBUG_Running();                // prints running ; as most items are setup at this point

}

void loop() {
ws.cleanupClients();                   // cleans up old websocket clients
wifi_checkup();                        // checks if wifi is still connected and starts AP as needed - wifi.h
if (restartRequired){OTA_Restart();}   // checks if the esp needs a reboot        - done via webpage / OTA - customserver.h
if (factoryRequired){deleteData();}    // checks if the esp needs a factory reset - done via webpage / OTA - customserver.h and wifisave.h

  if (WiFi.status() == WL_CONNECTED)   // check that we are connected to wifi before attempting mqtt
  {
    if (strcmp(mqtt_broker, "0") == 0) // no broker declared
    {}
    else                               // broker declared
    {
      if (!client.connected())
      {
        reconnect();
      }
     client.loop();
    }
  }

  if (connected_update == true) // if we are conencted to wifi and mqtt go green briefly
  {
    success();
  }

voltread();           // ina219.h   - read bus voltage
voltanimation();      // ina219.h   - handles the led aniamtions on under/over volt condition


if (ws_connected != 0)                 // we have a websocket client connected - send it data
{
  if ((millis() - lastUpdate) > 500)  // waiting an amount of time before resending
  {
    webSENDjson();                     // web_json.h - send json for websocket
  }
}


if (voltlockout == 0) // not in voltage lockout condition
{
  button.process();   // buttons.h  - process a button press

  handleportstate();  // press.h    - handles what state a port is in
  portsSTATE();       // press.h    - handles the ports being on, and led color
  overrideColor();    // neopixel.h - updates the neopixels when in override mode
}
else                  // turn ports off -- we are in an over / under voltage condition
{
  portlockout();      // press.h   - shuts off the ports in low / high voltage condition
}

} // end main loop

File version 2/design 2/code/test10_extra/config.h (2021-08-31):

#ifndef config_h
#define config_h

/* ----------------- General config -------------------------------- */

/* Debugging */
#define DEBUG_BUTTONS          true  // prints out button state
#define DEBUG_WIFIBUTTONS      true  // prints out webpage button state
#define DEBUG_JSON             false // prints out parsed json
#define DEBUG_voltage          false // prints out voltage infomation
#define DEBUG_current          false // prints out current information

uint16_t    portcurrent[4] = {0};  // max current for a port - max 3A (parts limit) // over ridden by config above


/* Varibles here are filled in by the config system */
char        host[32];
char        ssid[32];
char        password[64];

char        AP_SSID[32];
char        AP_PASS[64];
uint8_t     AP_CHANNEL  = 1; // not written over
uint8_t     AP_HIDDEN;
uint8_t     AP_MAX_CON  = 1; // not written over

char        mqtt_broker[32];
uint16_t    mqtt_port;
char        mqtt_username[32];
char        mqtt_password[32];

uint8_t     darkState;
char        htmltitle[32];
char        htmltype[32];
char        htmlcolor[10];
char        htmlhover[10];

uint16_t    systemcurrent;         // max current availble to the system (accounts for esp usage)***
uint16_t    portcurrent0;          // max current for a port - max 3A (parts limit) // will be used in json config
uint16_t    portcurrent1;          // max current for a port - max 3A (parts limit) // will be used in json config
uint16_t    portcurrent2;          // max current for a port - max 3A (parts limit) // will be used in json config
uint16_t    portcurrent3;          // max current for a port - max 3A (parts limit) // will be used in json config

uint8_t     brightness;            // set strip brightness

uint8_t     overrideMODE;          // are we allowing local control or only mqtt?
uint8_t     overrideWEB;           // can the web interface control the hub?

#endif

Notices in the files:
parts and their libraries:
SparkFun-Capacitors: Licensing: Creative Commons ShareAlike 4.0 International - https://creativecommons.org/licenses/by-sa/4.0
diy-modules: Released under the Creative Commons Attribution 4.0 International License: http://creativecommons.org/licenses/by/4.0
